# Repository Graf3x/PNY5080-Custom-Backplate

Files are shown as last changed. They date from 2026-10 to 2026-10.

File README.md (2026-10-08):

# PNY5080-Custom-Backplate

A white laser-cut backplate and a folded-metal cable cover for the **PNY GeForce RTX 5080 OC Triple Fan**. The 12V-2x6 power cable runs down a channel across the back of the card instead of sticking straight up out of the top.

Everything is generated from Python, and that python was FULLY vibe coded, make sure you use the test-prints on paper before you commit to getting something cut.  The cut files in this repo are the exact v94 files I ordered from SendCutSend, and the code rebuilds them to the micron. I take no liability if things do not line up for you. 

**The build story:** [Building a white, cable-hidden RTX 5080 with Claude](https://graf3x.github.io/PNY5080-Custom-Backplate/). How it went, including everything that didn't work.

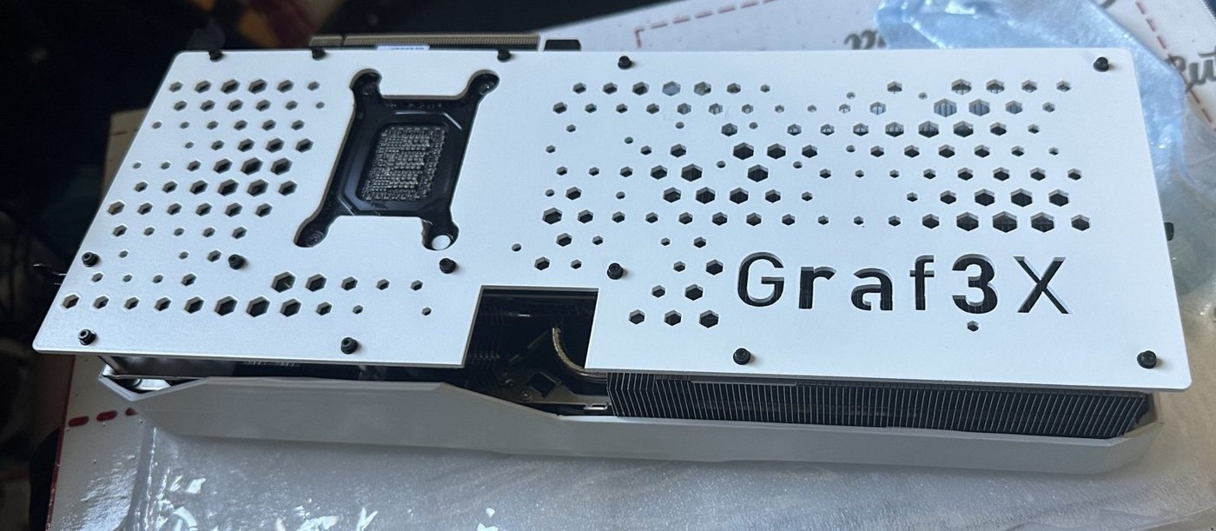
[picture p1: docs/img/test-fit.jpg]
First test fit: every screw seated


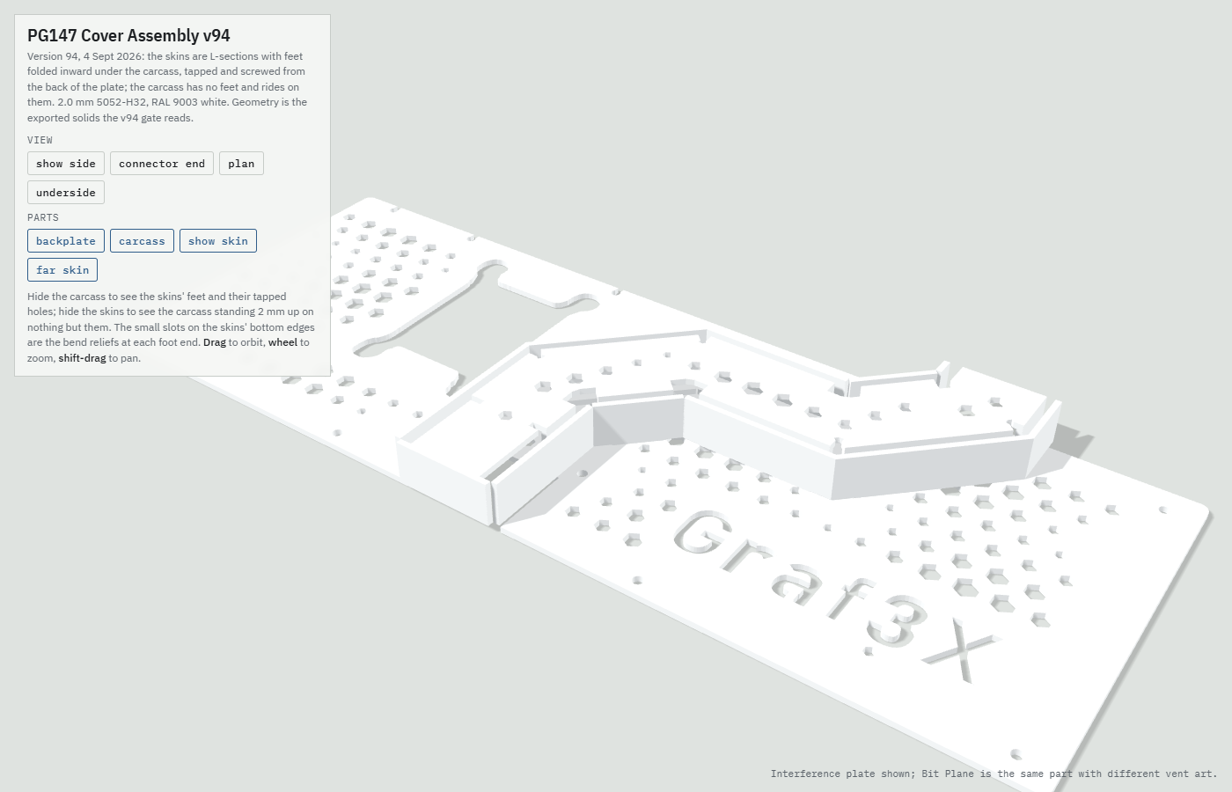
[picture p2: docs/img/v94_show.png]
v94 render
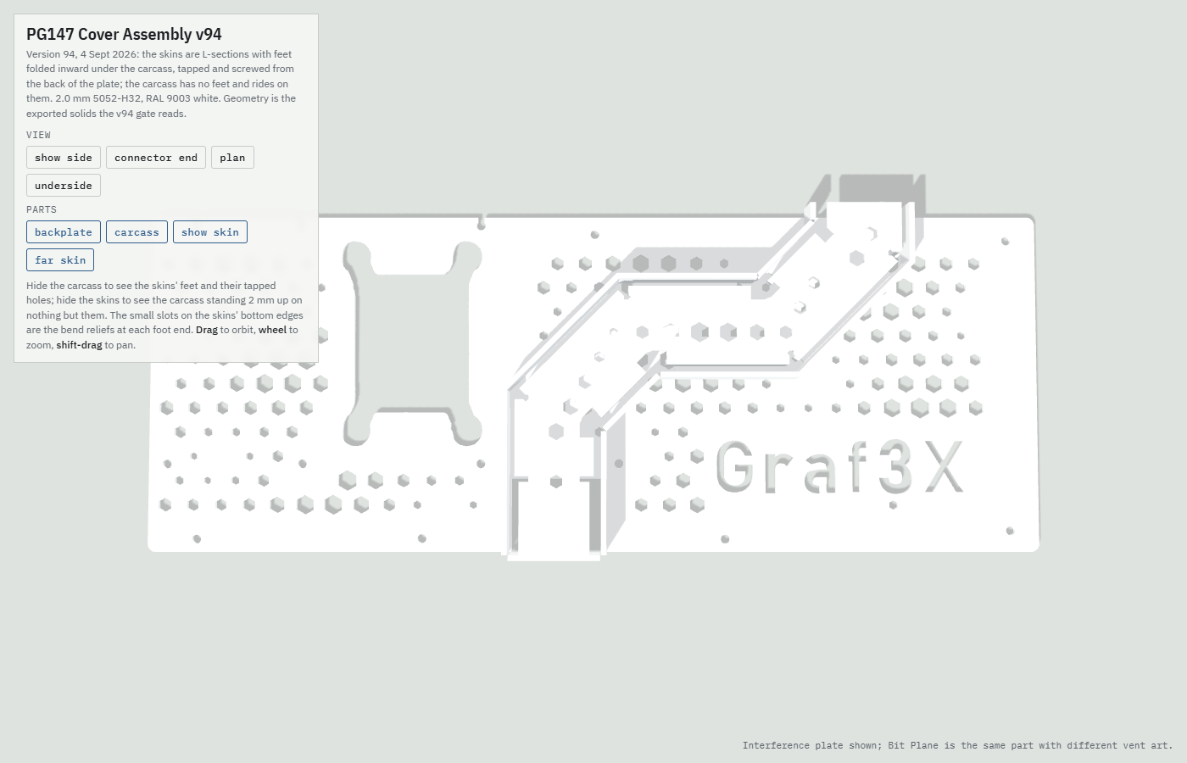
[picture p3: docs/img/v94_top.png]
v94 plan view
|  |  |
|---|---|
| The v94 assembly | Plan view, with the vent field running under the channel |

---

## Read this before you cut anything

- **It fits one card.** The 13 screw holes were measured from a PNY RTX 5080 OC Triple Fan (`VCG508016TFXPB1-O`, board **PG147 SKU 45**) using 300 dpi flatbed scans and calipers. Other 5080s, including other PNY models, are different boards. If yours isn't this exact card, assume the holes are wrong until you've proven otherwise.
- **Print the paper templates first.** Lay them on your card. If every hole and edge doesn't line up on paper, it won't line up in metal. A sheet of printer paper costs about 1.4 cents. A plate costs about $68 for just the backplate (not the channel) and a week of shipping.
- **You are modifying a graphics card.** Taking the stock backplate off, re-padding and re-fitting are on you. No warranty of any kind comes with these files.

## What's in here

```
out/production_v94/upload/   the files you upload to SendCutSend, plus ORDER_SHEET_v94.txt
out/production_v94/          the same parts with notes drawn beside them, for reading
out/production_v94/templates_1to1_letter.pdf / _a4.pdf   paper templates, print at 100%
out/render_v94/              3D files of the assembly (GLB) for looking at
reference/v94-as-ordered/    a frozen copy of the exact files that were cut
cad/                         the Python that generates all of it
tools/print_templates.py     draws 1:1 templates from any folder of DXFs
tools/compare_dxf.py         checks two sets of cut files for identical geometry
```

## The parts

All five parts are **2.0 mm (0.080 in) 5052-H32 aluminium**, powder coated **RAL 9003 signal white**. Every part is over SendCutSend's 1 inch minimum for powder coat.

| File | What it is |
|---|---|
| `backplate_interference_v94.dxf` | Backplate with the Interference vent field |
| `backplate_bit_plane_v94.dxf` | The same backplate with the Bit Plane vent field. Order one or both. |
| `carcass_v94.dxf` | The cable channel itself. One piece, 10 folds, all 90° and all the same way. |
| `skin_show_v94.dxf` | The outer wall on the logo side. 4 × 45° folds plus 3 inward feet, 5 tapped holes. |
| `skin_far_v94.dxf` | The outer wall on the other side. 4 × 45° folds plus 4 inward feet, 6 tapped holes. |

The DXF layers tell the vendor everything:

- `CUT` is the laser line.
- `BEND_UP_45`, `BEND_DOWN_45` and `BEND_DOWN_90` are dashed fold lines, with the direction and angle in the name. UP means toward the reader of the file.
- `TAP` is drill and tap, not laser.

`ORDER_SHEET_v94.txt` spells all of this out for the order.

### Hardware

| Item | Used for |
|---|---|
| 11 × M2.5 × 0.45 × 4 mm flat head screws (90°) | Plate to the skins' feet, driven from the back |
| 3M VHB 4991, 2.30 mm, grey | Carcass to the inner faces of the skins. The grey reads as a shadow line. |
| M2 screws | Plate to the card's 13 mounting points |
| [Ktehloy metric threaded insert kit](https://www.amazon.com/dp/B0CLKDPN65) | Standoffs at the mounting points that don't touch the PCB |
| Nylon washers, or silicone washers cut to size | Spacers at the mounting points on the PCB itself |

The stock plate was dimpled to a different depth at each screw, and a flat plate can't do that. So every mounting point needs its own spacer height. Set each one to fit before you tighten anything, or the screws will pull the plate into a bow. The clearance holes are 3.2 mm on purpose, so a washer under each screw head helps spread the load.

The cover was designed around a 180° 12V-2x6 adapter about 30 × 25 × 12.6 mm and a cable bundle about 22 × 6 mm.

## Quick start: order exactly what I built

1. Print `out/production_v94/templates_1to1_letter.pdf` (or `_a4.pdf`) at **100% / Actual size**. Never "Fit to page".
2. Measure the 100 mm bar on each sheet with a ruler. If it isn't 100 mm, your printer scaled it. Fix that first.
3. Lay the backplate sheets on your card **ink up** and check every screw hole. The backplate spans two sheets that overlap. Line them up on the dashed seam marks and don't butt the paper edges together.
4. Cut out and fold the carcass and skins in card stock. Fold on the dashed lines in the direction each one is labelled. UP means toward you, the printed side.
5. Upload the five DXFs in `out/production_v94/upload/` to SendCutSend and follow `ORDER_SHEET_v94.txt`.

### Assembly

1. Countersink the backplate's 11 cover holes from the **back**, by hand, after coating (90°). SendCutSend won't countersink stock this thin.
2. Stand each skin on the plate with its feet inward. Drive the M2.5 flat heads from the back of the plate into the tapped feet.
3. Put the VHB tape on the skins' inner faces, drop the carcass in between them onto the feet, and press.
4. Fit the plate to the card with the M2 screws. Use threaded inserts as standoffs where the plate meets the cooler or brackets, and nylon or silicone washers where it meets the PCB.

## Rebuilding the files yourself

You need Python 3.12. The library versions in `requirements.txt` are pinned to the ones that built the cut files.

```bash
python -m venv .venv
.venv/Scripts/activate            # Windows (on macOS/Linux: source .venv/bin/activate)
pip install -r requirements.txt

python cad/make_v94.py            # the five DXFs + ORDER_SHEET into out/production_v94/
python cad/gate_v94.py            # the release checks: must end with ALL CHECKS PASS
python cad/export_v94.py          # 3D files into out/render_v94/
python tools/print_templates.py   # paper templates (add --paper a4 for A4)
```

To confirm your build matches what was actually cut:

```bash
python tools/compare_dxf.py out/production_v94/upload reference/v94-as-ordered
```

### Fonts

The wordmark is set in **Bahnschrift**, which ships with Windows 10 and 11. Fonts are not included in this repo because Microsoft's fonts can't be redistributed. `cad/config.py` looks for the font in the usual Windows, macOS and Linux font folders. To use a font file anywhere else:

```bash
set PNY5080_FONT=C:\path\to\YourFont.ttf      # Windows
export PNY5080_FONT=/path/to/YourFont.ttf     # macOS / Linux
```

## Customizing

The safe loop for **any** change is the same every time:

1. Edit the setting.
2. `python cad/vent_ocr.py` if you touched the logo. Every design must say **PASS**.
3. `python cad/make_v94.py`
4. `python cad/gate_v94.py`. It must end with **ALL CHECKS PASS**. The gate re-measures the actual files for metal thinner than 2 mm, holes too close to bends, feet that collide when folded and more. It also plants defects on purpose to prove its own checks still work.
5. `python tools/print_templates.py` and do the paper test on your card again.

### Change the logo text

In `cad/config.py`:

```python
class BRAND:
    TEXT = "Graf3X"
```

Use letters and digits only. The readability check has templates for A–Z, a–z and 0–9 and nothing else. After you change it, run `python cad/vent_ocr.py`. It renders each backplate, reads the logo back with a simple OCR and fails if any letter reads as something else.

It will fail sometimes, and that's the point. Some real results:

| Text | Result |
|---|---|
| `Graf3X`, `Grafex`, `PG147` | PASS on all three designs |
| `Josh` | FAIL. Reads "JnSh": the little bridge that holds the middle of the "o" in place makes it look like an "n". |
| `JOSH` | FAIL. Reads "J0SH": in Bahnschrift a capital O and a zero are nearly the same shape. |

When it fails, try one of these:

- Fewer characters, so each one is bigger.
- A wider mark. `MARK_W` in `cad/vent_iterate.py` is the mark's width in mm (90 by default) and `MARK_CENTRE` is where it sits on the plate.
- Different letters or capitalization. Watch out for pairs that look alike in your font, such as O and 0.

The design names in the code still say "Graf3X" (for example `"Interference / Graf3X, OCR"`). They're only labels. The text that gets cut comes from `BRAND.TEXT`.

### Change the font

Point `BRAND.FONT` in `cad/config.py` at a `.ttf` file, or set `PNY5080_FONT`. Not every font can be cut in 2 mm aluminium. Thin strokes and tight counters leave metal webs under 2 mm, and the gate will catch them. Arial Bold failed for exactly this reason, which is why the plate uses Bahnschrift. Bold, open, geometric faces have the best odds.

### Pick which vent designs become backplates

`PLATES` in `cad/make_production.py` lists the designs the build cuts:

```python
PLATES = ("Interference / Graf3X, OCR", "Bit Plane / Graf3X, OCR")
```

A third verified design, `"Interference long wave / Graf3X, OCR"`, is defined in `cad/vent_ocr.py`. Add it to `PLATES` and the build will emit a third backplate. The vent field stays clear of the thermal pads, the card screws and the area where the cover is attached.

### Change the finish

Colour and finish only matter on the order. Any powder SendCutSend offers will work. Keep every visible part on one order, because powder batches drift.

### Fitting a different card

This is real work, not a setting. The hole positions are in `cad/hole_pattern.py`, measured from one plate. The outline, die window and connector notch are in `cad/backplate_v3.py` and `cad/die_window.py`, and the cable route is in `cad/cover_ribbon.py` and `cad/v94.py`. If you go down this road, measure your own stock backplate, change those numbers, and lean hard on the paper templates.

## License

**CC BY-NC 4.0.** You can use, change and share these files for non-commercial purposes as long as you give credit. Selling the files or parts made from them is not allowed. See `LICENSE` for the full terms. © 2026 Data Disruptors LLC (Grafex).

PNY, NVIDIA, GeForce, SendCutSend, 3M and VHB are trademarks of their respective owners. This project is not affiliated with or endorsed by any of them.

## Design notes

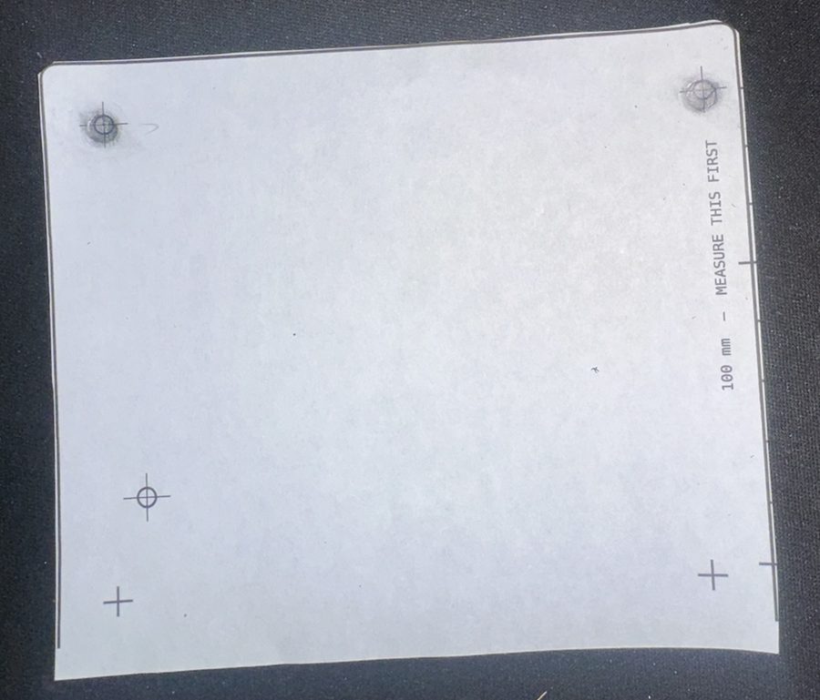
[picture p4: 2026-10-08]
docs/writeup-img/14-79dea924b6.jpg

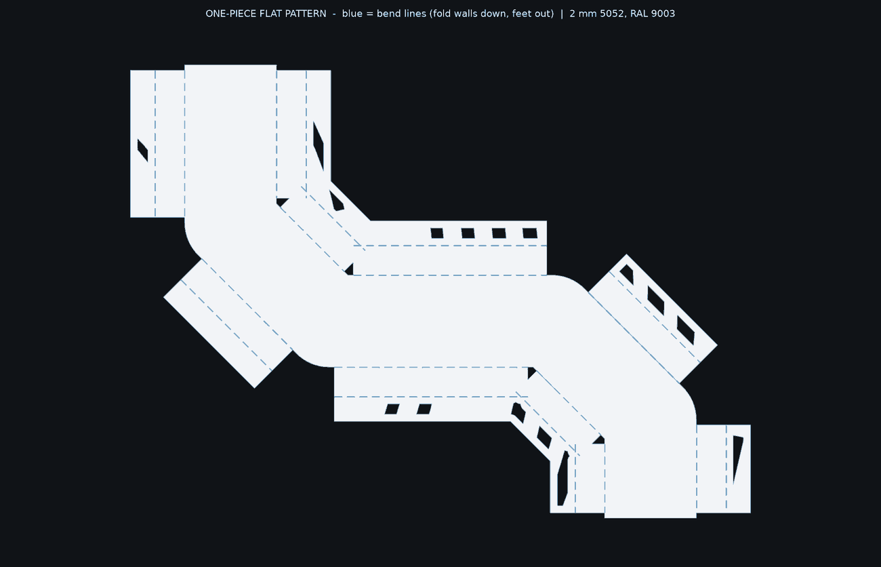
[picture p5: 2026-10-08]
docs/writeup-img/04-ba247a8842.png

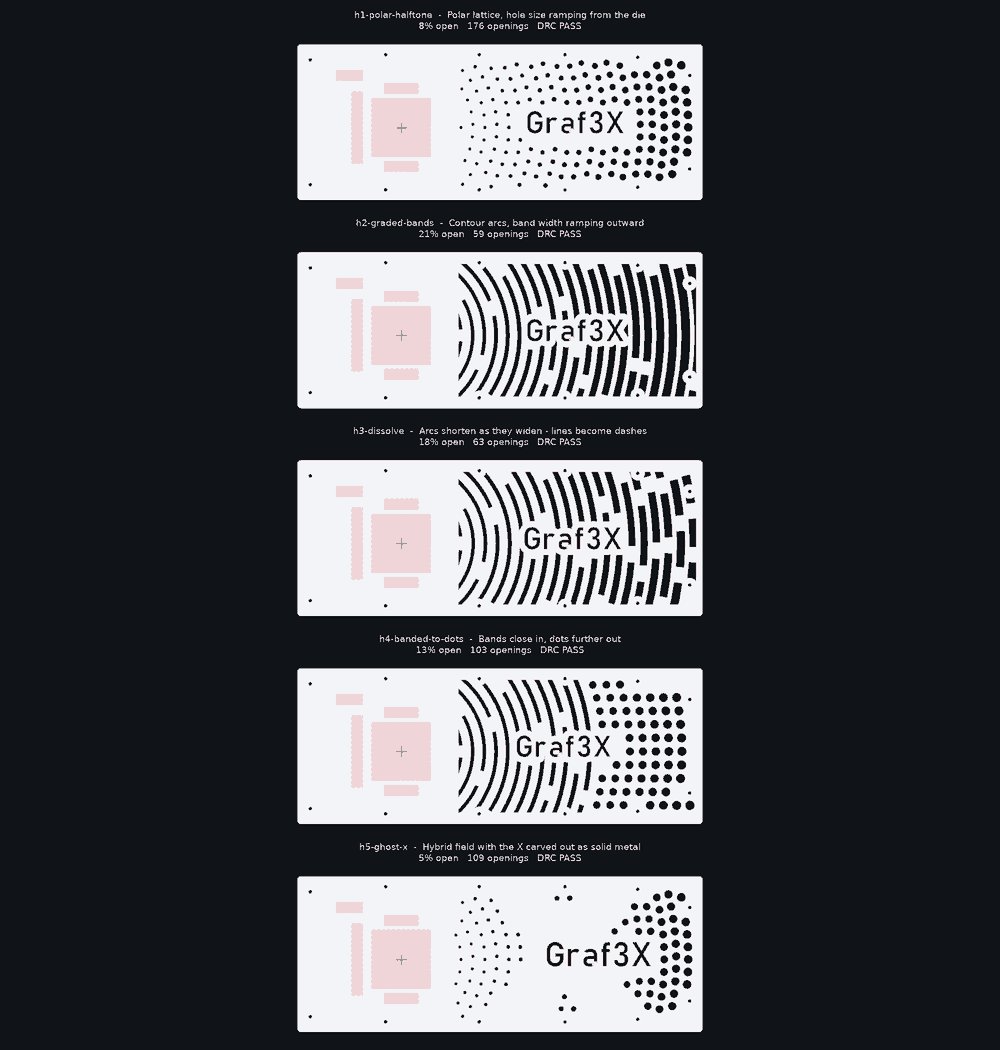
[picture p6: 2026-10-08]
docs/writeup-img/06-0ba101b55b.png

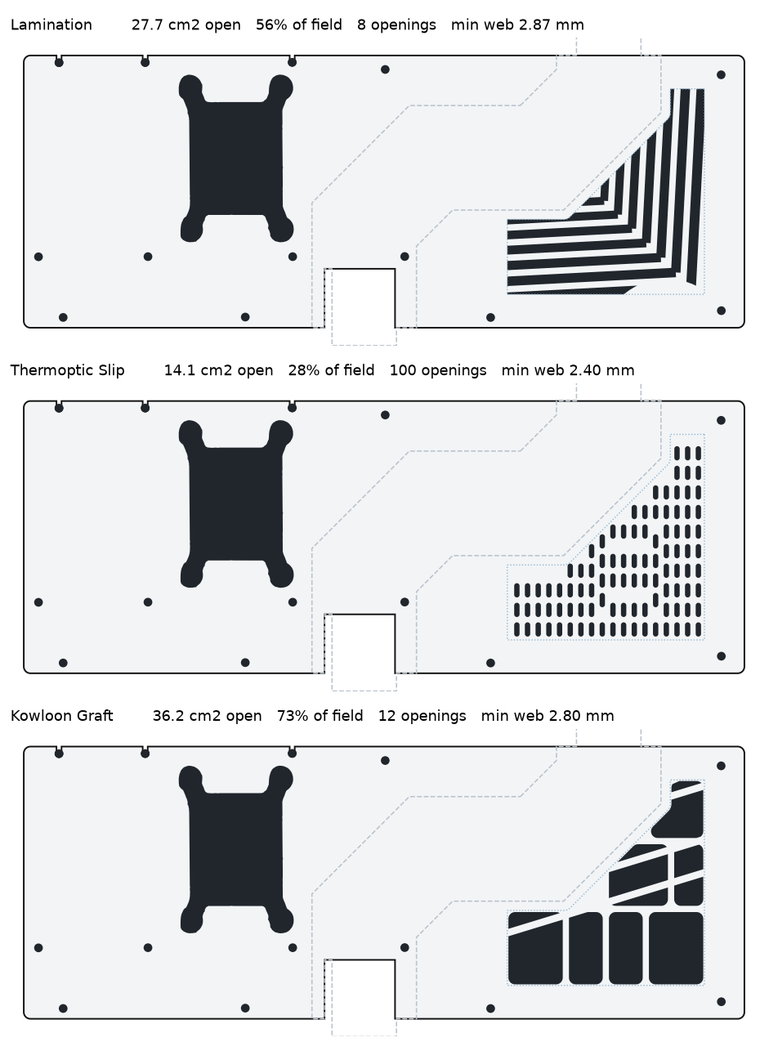
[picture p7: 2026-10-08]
docs/writeup-img/17-3ee478ab25.png

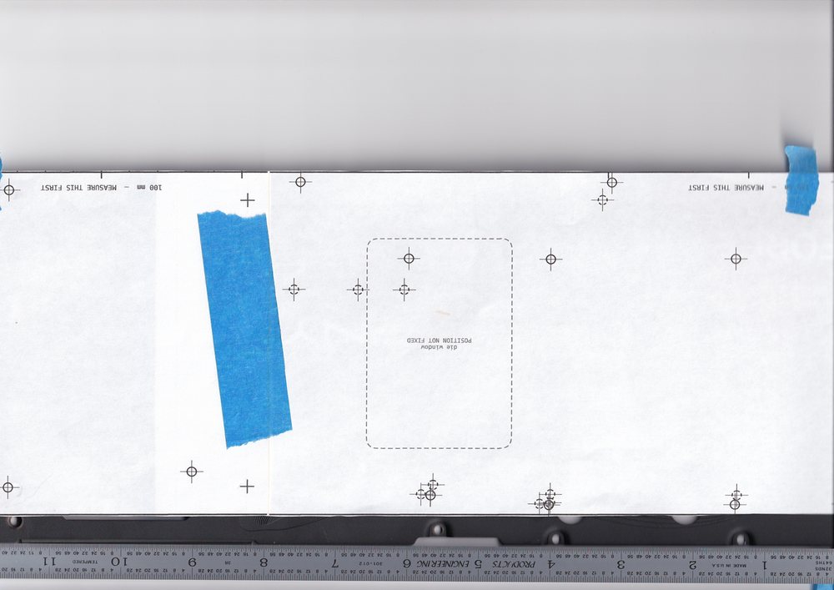
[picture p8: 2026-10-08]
docs/writeup-img/10-968c5388d2.jpg

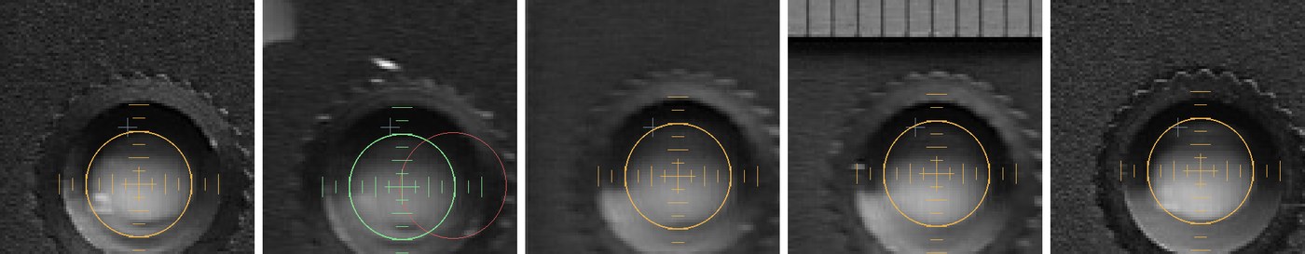
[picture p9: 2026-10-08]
docs/writeup-img/16-f5f942da19.jpg

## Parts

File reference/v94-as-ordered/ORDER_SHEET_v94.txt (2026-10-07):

PG147 COVER - ORDER SHEET v94  (SendCutSend)

MATERIAL  5052-H32 aluminium, 0.080 in (2.0 mm), all five parts.
FINISH    powder coat RAL 9003 signal white, matte or gloss - the
          same on all five. Every part is now over the 1 in powder
          minimum: skins 27.35 mm (1.077 in) wide in the flat.
QUANTITY  1 of each: backplate_bit_plane_v94.dxf, backplate_interference_v94.dxf, carcass_v94.dxf, skin_far_v94.dxf, skin_show_v94.dxf

LAYERS    CUT = laser.  BEND_UP_45 / BEND_DOWN_45 / BEND_DOWN_90 =
          dashed fold lines, direction + angle in the name. UP =
          toward the reader of the file. TAP = drill + tap, not laser.

BACKPLATES  2, interchangeable. 11 x dia 2.90 clearance for the
          cover screws, on CUT. No slots, no taps. The owner
          countersinks these from the BACK by hand after coating
          (90 deg, M2.5 x 0.45 flat head) - the vendor countersinks
          0.125 in and thicker only.

CARCASS   one piece, 10 folds, all 90 deg, all BEND_DOWN_90: nine
          walls and the end cap, all away from the reader. NO feet.
          16 roof vents on CUT. It stands on the skins' feet and is
          bonded to the skins with 3M VHB 4991, 2.30 mm, grey.

SKIN SHOW  199.63 x 27.35 mm flat. 4 x 45 deg folds (two each way) +
          3 foot folds at 90 deg on BEND_DOWN_90, INWARD. 5 tapped
          M2.5 x 0.45 on layer TAP. 6 relief slots 2.0 x 3.47 on the
          bottom edge, one at each foot end - required.
SKIN FAR   199.63 x 27.35 mm flat. 4 x 45 deg folds (two each way) +
          4 foot folds at 90 deg on BEND_DOWN_90, INWARD. 6 tapped
          M2.5 x 0.45 on layer TAP. 8 relief slots 2.0 x 3.47 on the
          bottom edge, one at each foot end - required.

ASSEMBLY  1. Countersink the plate's 11 holes from the back.
          2. Stand each skin on the plate, feet inward, and drive
             M2.5 x 0.45 x 4 flat heads from the back into the feet.
          3. Apply 3M VHB 4991, 2.30 mm, grey to the skins' inner faces,
             drop the carcass in between them onto the feet, press.
          Stack: plate 2.00 + skin foot 2.00 (+coats) = carcass wall
          bottom at 4.45; roof top at 16.95; cable clear height 10.65.
HARDWARE  11 x M2.5 x 0.45 x 4 mm flat head (90 deg), stainless or black.

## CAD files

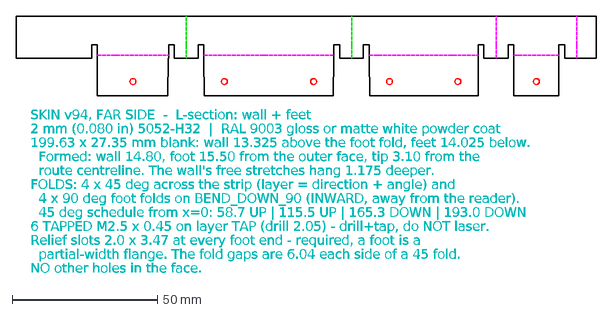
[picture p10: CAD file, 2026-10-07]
out/production_v94/skin_far_v94.dxf
SKIN v94, FAR SIDE - L-section: wall + feet
2 mm (0.080 in) 5052-H32 | RAL 9003 gloss or matte white powder coat
199.63 x 27.35 mm blank: wall 13.325 above the foot fold, feet 14.025 below.
Formed: wall 14.80, foot 15.50 from the outer face, tip 3.10 from the
route centreline. The wall's free stretches hang 1.175 deeper.
FOLDS: 4 x 45 deg across the strip (layer = direction + angle) and
4 x 90 deg foot folds on BEND_DOWN_90 (INWARD, away from the reader).
45 deg schedule from x=0: 58.7 UP | 115.5 UP | 165.3 DOWN | 193.0 DOWN
6 TAPPED M2.5 x 0.45 on layer TAP (drill 2.05) - drill+tap, do NOT laser.
Relief slots 2.0 x 3.47 at every foot end - required, a foot is a
partial-width flange. The fold gaps are 6.04 each side of a 45 fold.
NO other holes in the face.

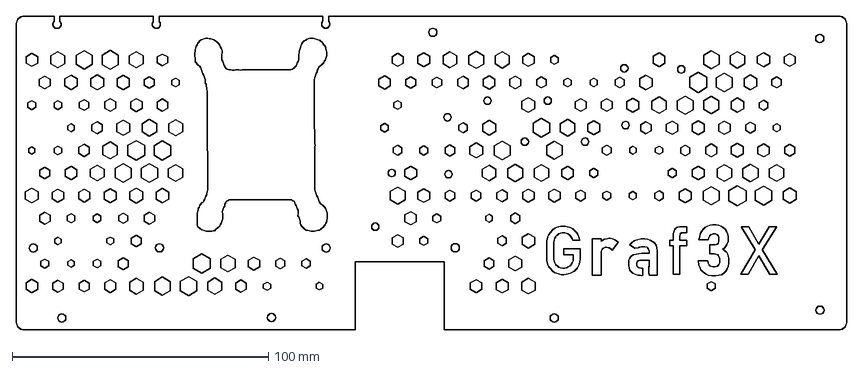
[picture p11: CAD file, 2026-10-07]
out/production_v94/upload/backplate_interference_v94.dxf
324.0 x 122.4 mm

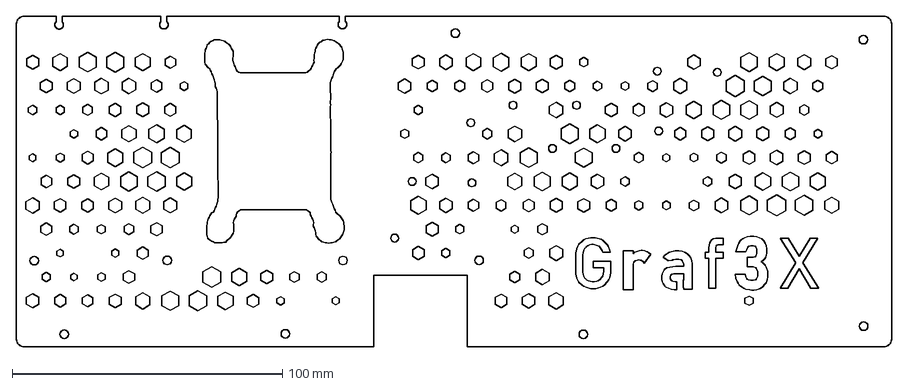
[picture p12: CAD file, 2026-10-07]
reference/v94-as-ordered/backplate_interference_v94.dxf
324.0 x 122.4 mm

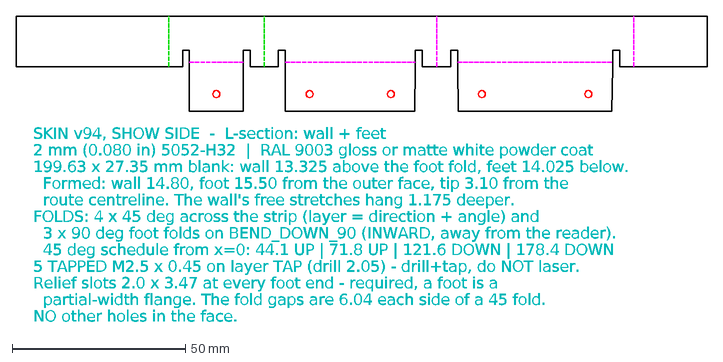
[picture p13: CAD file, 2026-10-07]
out/production_v94/skin_show_v94.dxf
SKIN v94, SHOW SIDE - L-section: wall + feet
2 mm (0.080 in) 5052-H32 | RAL 9003 gloss or matte white powder coat
199.63 x 27.35 mm blank: wall 13.325 above the foot fold, feet 14.025 below.
Formed: wall 14.80, foot 15.50 from the outer face, tip 3.10 from the
route centreline. The wall's free stretches hang 1.175 deeper.
FOLDS: 4 x 45 deg across the strip (layer = direction + angle) and
3 x 90 deg foot folds on BEND_DOWN_90 (INWARD, away from the reader).
45 deg schedule from x=0: 44.1 UP | 71.8 UP | 121.6 DOWN | 178.4 DOWN
5 TAPPED M2.5 x 0.45 on layer TAP (drill 2.05) - drill+tap, do NOT laser.
Relief slots 2.0 x 3.47 at every foot end - required, a foot is a
partial-width flange. The fold gaps are 6.04 each side of a 45 fold.
NO other holes in the face.

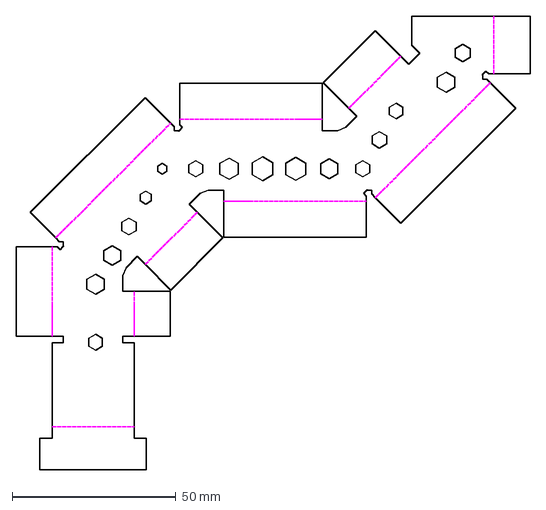
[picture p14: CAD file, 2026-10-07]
out/production_v94/upload/carcass_v94.dxf
157.0 x 138.4 mm

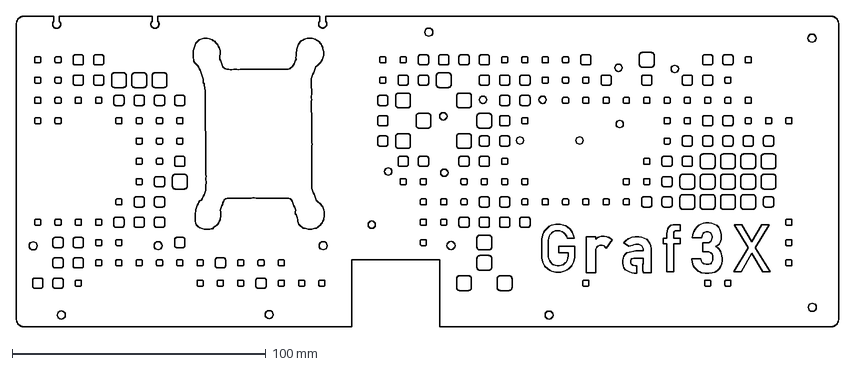
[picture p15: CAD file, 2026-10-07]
reference/v94-as-ordered/backplate_bit_plane_v94.dxf
324.0 x 122.4 mm

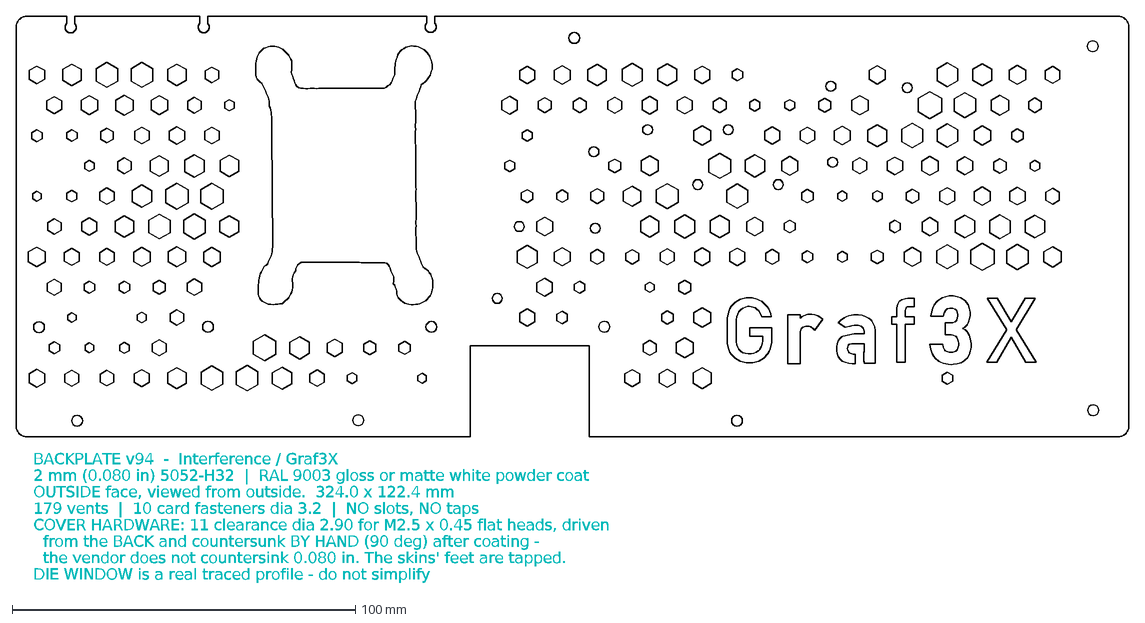
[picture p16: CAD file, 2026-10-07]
out/production_v94/backplate_interference_v94.dxf
BACKPLATE v94 - Interference / Graf3X
2 mm (0.080 in) 5052-H32 | RAL 9003 gloss or matte white powder coat
OUTSIDE face, viewed from outside. 324.0 x 122.4 mm
179 vents | 10 card fasteners dia 3.2 | NO slots, NO taps
COVER HARDWARE: 11 clearance dia 2.90 for M2.5 x 0.45 flat heads, driven
from the BACK and countersunk BY HAND (90 deg) after coating -
the vendor does not countersink 0.080 in. The skins' feet are tapped.
DIE WINDOW is a real traced profile - do not simplify

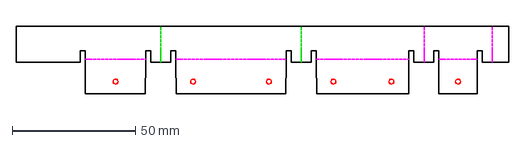
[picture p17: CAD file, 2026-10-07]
out/production_v94/upload/skin_far_v94.dxf
199.6 x 27.4 mm

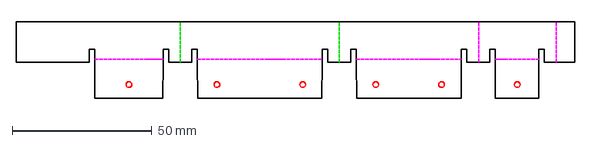
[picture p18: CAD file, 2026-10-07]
reference/v94-as-ordered/skin_far_v94.dxf
199.6 x 27.4 mm

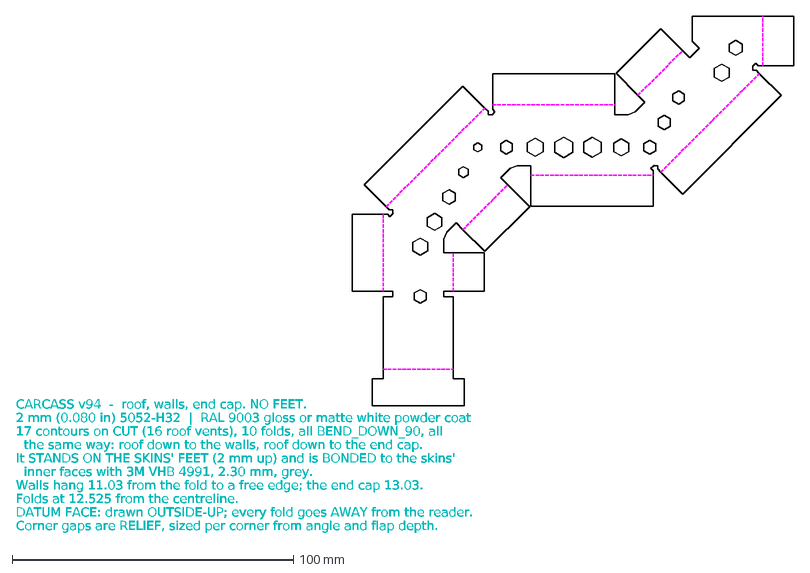
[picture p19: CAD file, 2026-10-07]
out/production_v94/carcass_v94.dxf
CARCASS v94 - roof, walls, end cap. NO FEET.
2 mm (0.080 in) 5052-H32 | RAL 9003 gloss or matte white powder coat
17 contours on CUT (16 roof vents), 10 folds, all BEND_DOWN_90, all
the same way: roof down to the walls, roof down to the end cap.
It STANDS ON THE SKINS' FEET (2 mm up) and is BONDED to the skins'
inner faces with 3M VHB 4991, 2.30 mm, grey.
Walls hang 11.03 from the fold to a free edge; the end cap 13.03.
Folds at 12.525 from the centreline.
DATUM FACE: drawn OUTSIDE-UP; every fold goes AWAY from the reader.
Corner gaps are RELIEF, sized per corner from angle and flap depth.

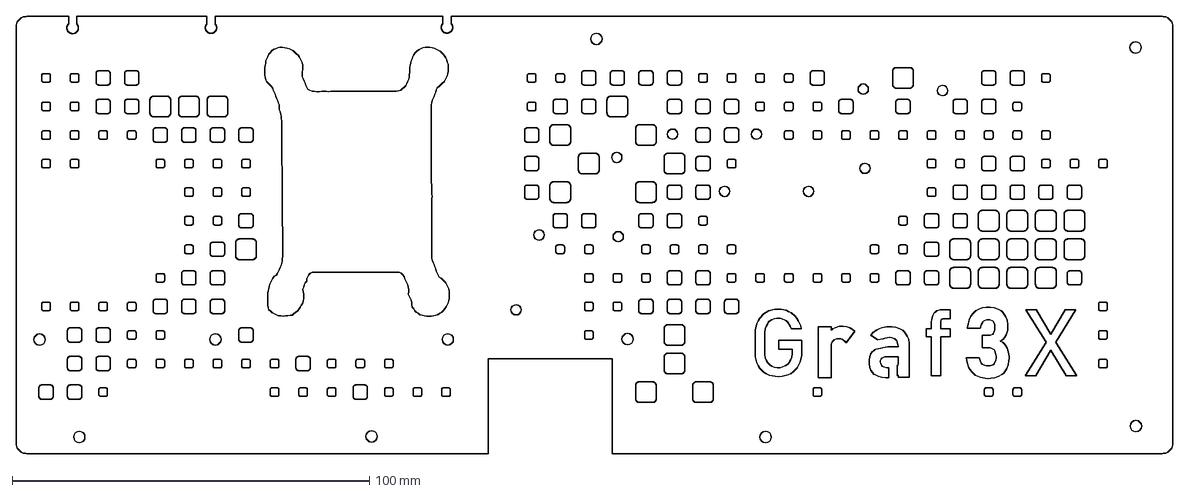
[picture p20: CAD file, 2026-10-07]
out/production_v94/upload/backplate_bit_plane_v94.dxf
324.0 x 122.4 mm

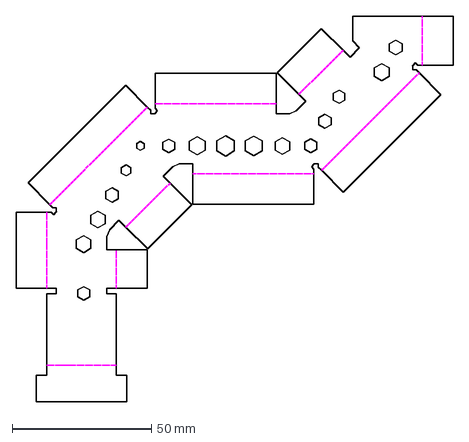
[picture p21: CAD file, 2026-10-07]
reference/v94-as-ordered/carcass_v94.dxf
157.0 x 138.4 mm

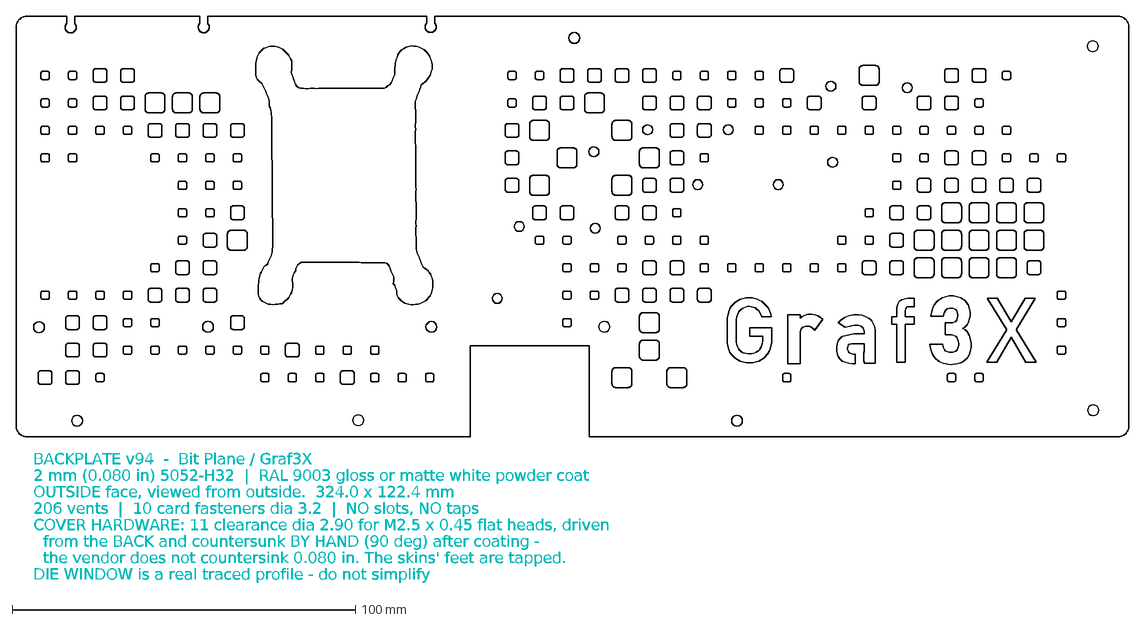
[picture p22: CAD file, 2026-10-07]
out/production_v94/backplate_bit_plane_v94.dxf
BACKPLATE v94 - Bit Plane / Graf3X
2 mm (0.080 in) 5052-H32 | RAL 9003 gloss or matte white powder coat
OUTSIDE face, viewed from outside. 324.0 x 122.4 mm
206 vents | 10 card fasteners dia 3.2 | NO slots, NO taps
COVER HARDWARE: 11 clearance dia 2.90 for M2.5 x 0.45 flat heads, driven
from the BACK and countersunk BY HAND (90 deg) after coating -
the vendor does not countersink 0.080 in. The skins' feet are tapped.
DIE WINDOW is a real traced profile - do not simplify

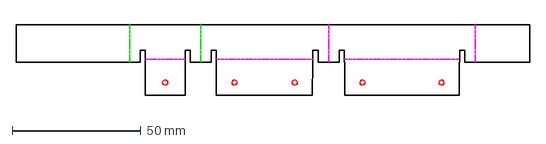
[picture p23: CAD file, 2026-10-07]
out/production_v94/upload/skin_show_v94.dxf
199.6 x 27.4 mm

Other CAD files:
reference/v94-as-ordered/skin_show_v94.dxf

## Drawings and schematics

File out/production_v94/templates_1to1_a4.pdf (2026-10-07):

# backplate_bit_plane_v94 - sheet 1 of 2

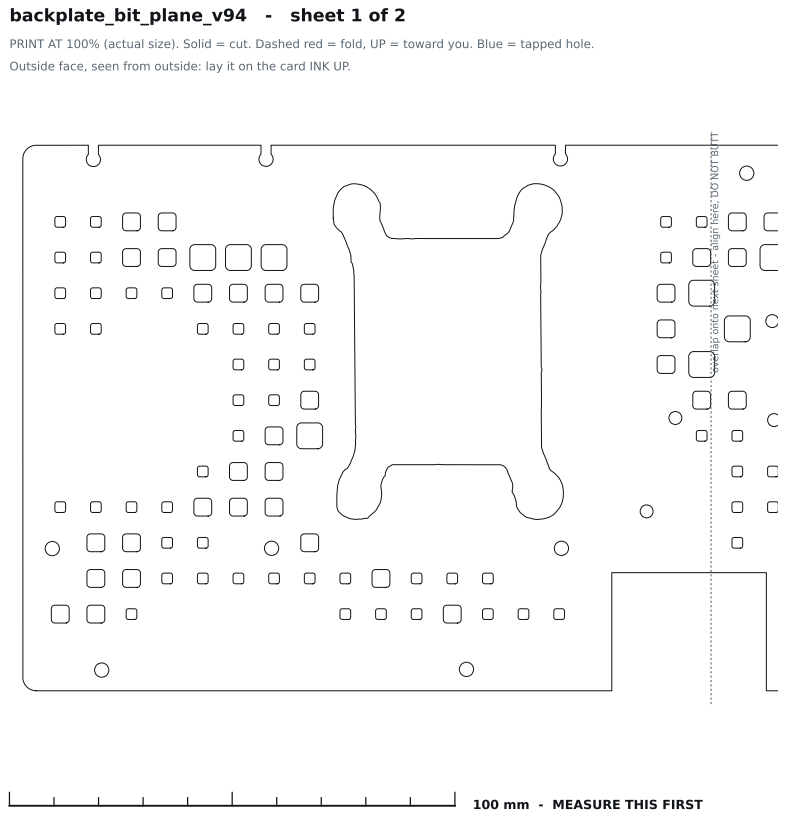
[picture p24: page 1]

PRINT AT 100% (actual size). Solid = cut. Dashed red = fold, UP = toward you. Blue = tapped hole.

Outside face, seen from outside: lay it on the card INK UP.

overlap onto next sheet - align here, DO NOT BUTT

100 mm - MEASURE THIS FIRST

# backplate_bit_plane_v94 - sheet 2 of 2

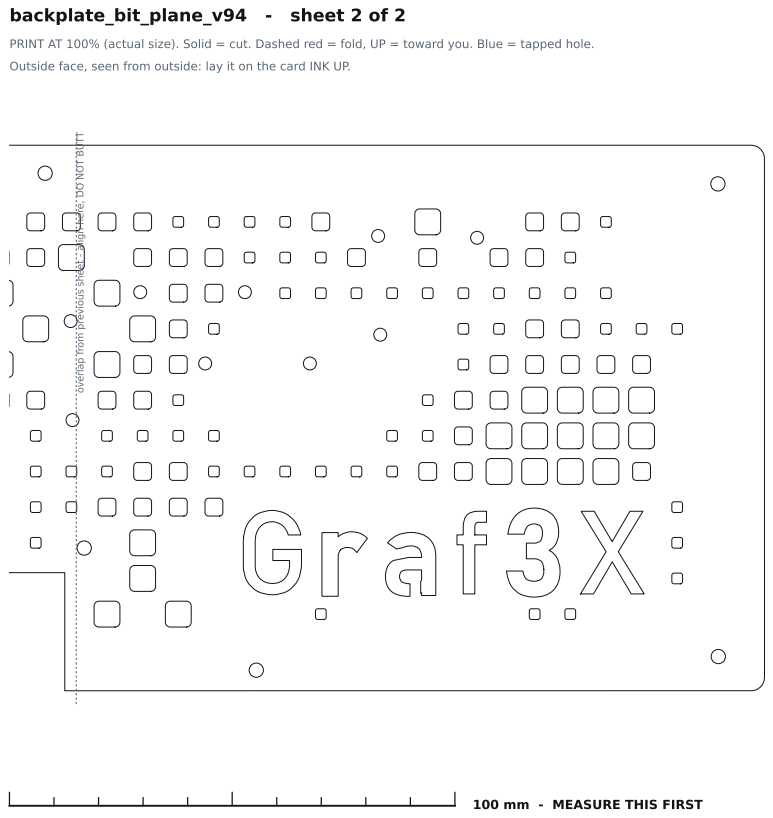
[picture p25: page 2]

PRINT AT 100% (actual size). Solid = cut. Dashed red = fold, UP = toward you. Blue = tapped hole.

Outside face, seen from outside: lay it on the card INK UP.

overlap from previous sheet - align here, DO NOT BUTT

100 mm - MEASURE THIS FIRST

# backplate_interference_v94 - sheet 1 of 2

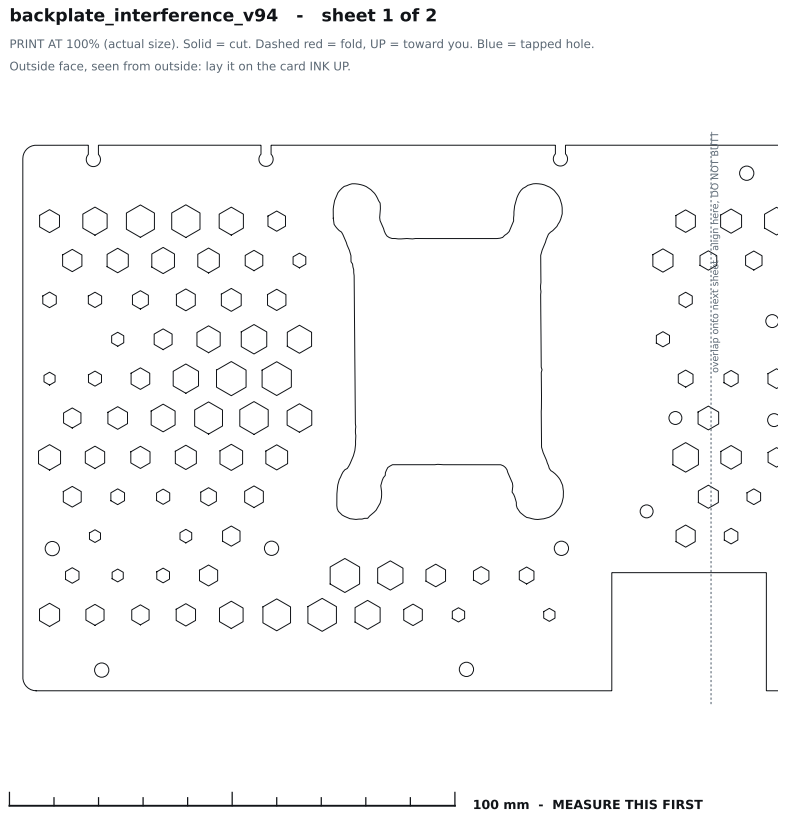
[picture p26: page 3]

PRINT AT 100% (actual size). Solid = cut. Dashed red = fold, UP = toward you. Blue = tapped hole.

Outside face, seen from outside: lay it on the card INK UP.

overlap onto next sheet - align here, DO NOT BUTT

100 mm - MEASURE THIS FIRST

# backplate_interference_v94 - sheet 2 of 2

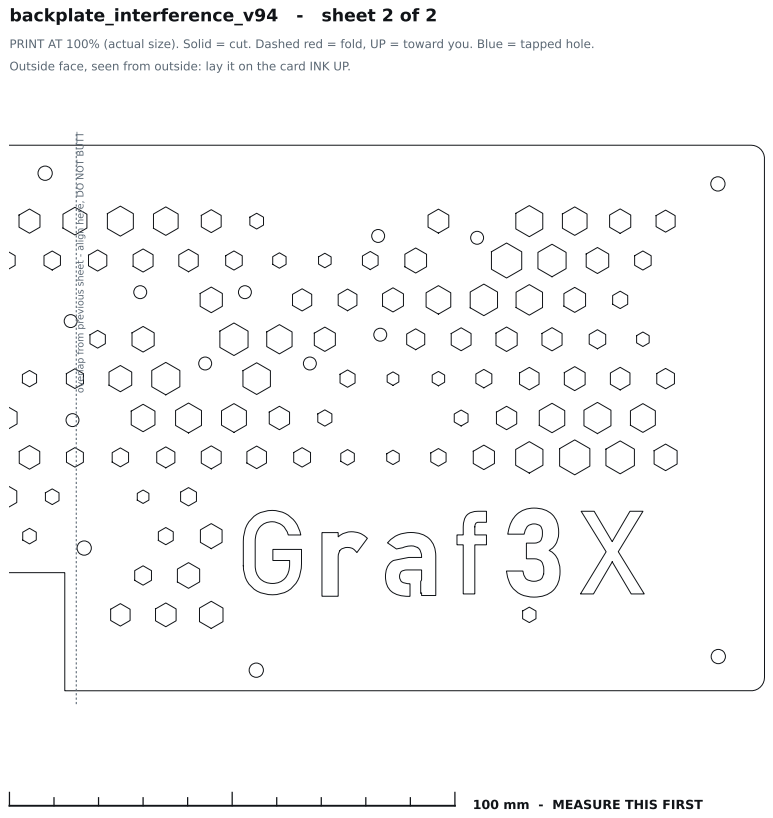
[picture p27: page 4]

PRINT AT 100% (actual size). Solid = cut. Dashed red = fold, UP = toward you. Blue = tapped hole.

Outside face, seen from outside: lay it on the card INK UP.

overlap from previous sheet - align here, DO NOT BUTT

100 mm - MEASURE THIS FIRST

# carcass_v94

PRINT AT 100% (actual size). Solid = cut. Dashed red = fold, UP = toward you. Blue = tapped hole.

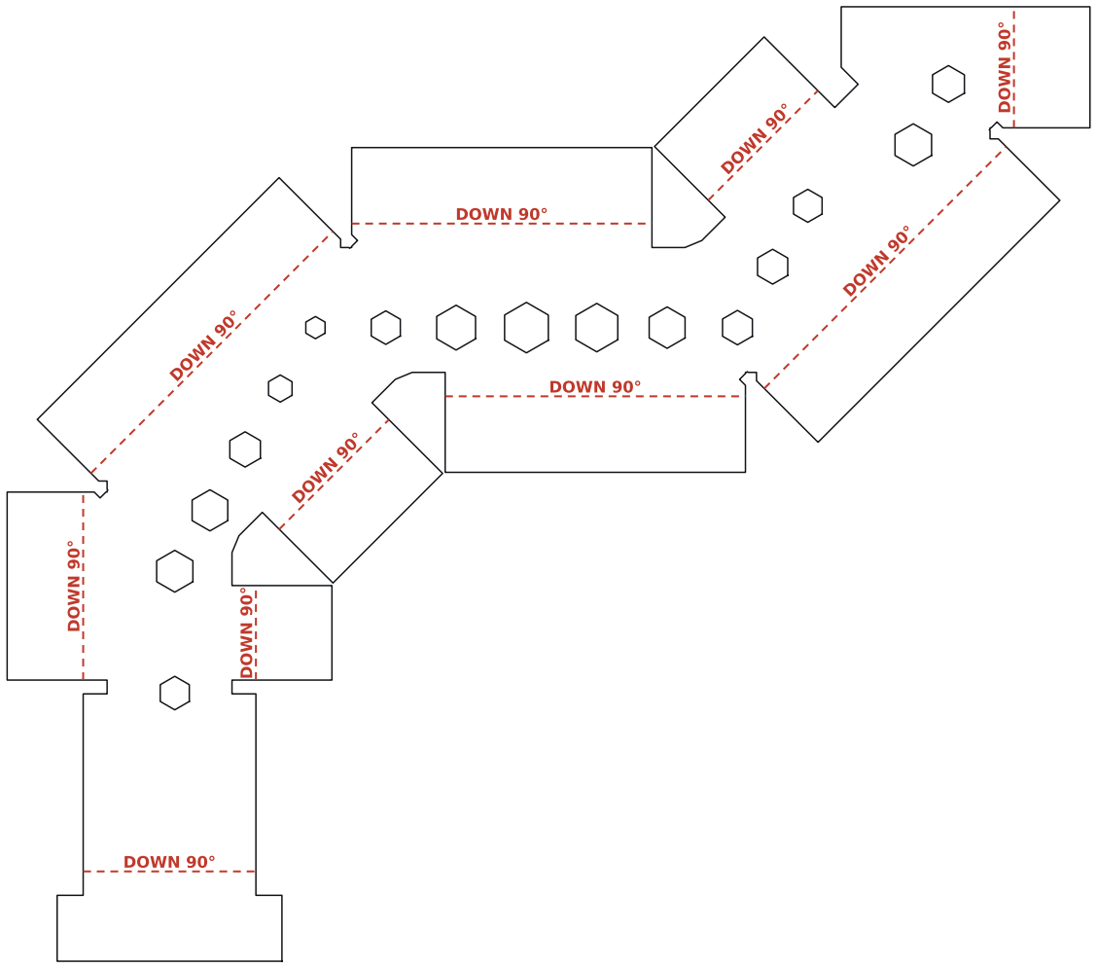
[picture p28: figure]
DOWN 90°

### 100 mm - MEASURE THIS FIRST

# skin_far_v94

PRINT AT 100% (actual size). Solid = cut. Dashed red = fold, UP = toward you. Blue = tapped hole.

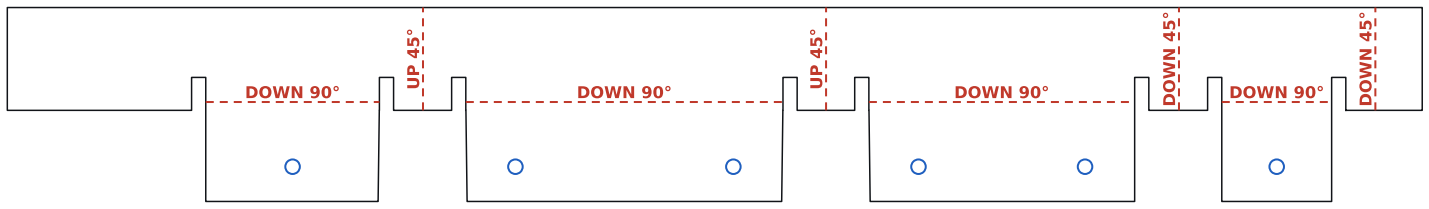
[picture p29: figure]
DOWN 45°; DOWN 90°

### 100 mm - MEASURE THIS FIRST

# skin_show_v94

PRINT AT 100% (actual size). Solid = cut. Dashed red = fold, UP = toward you. Blue = tapped hole.

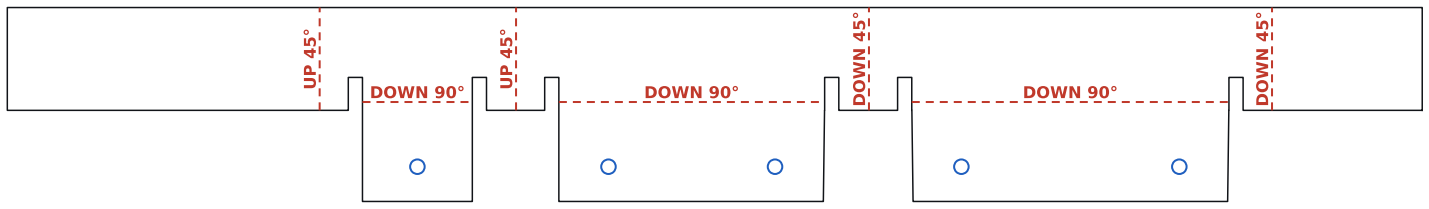
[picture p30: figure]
DOWN 45°; DOWN 90°

### 100 mm - MEASURE THIS FIRST

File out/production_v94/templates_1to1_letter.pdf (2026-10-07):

# backplate_bit_plane_v94 - sheet 1 of 2

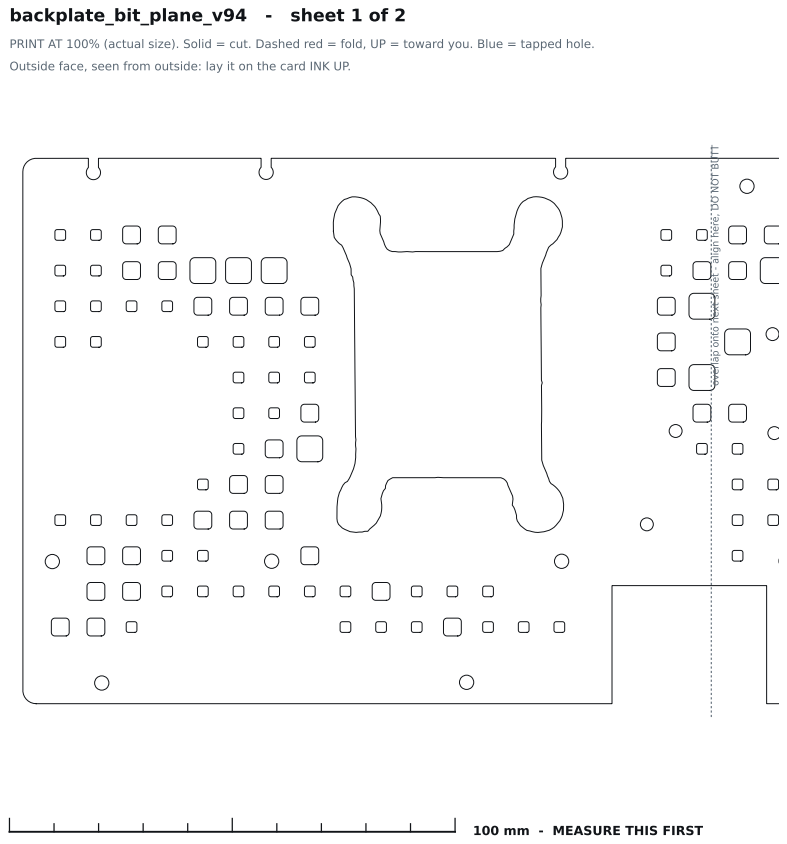
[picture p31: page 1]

PRINT AT 100% (actual size). Solid = cut. Dashed red = fold, UP = toward you. Blue = tapped hole.

Outside face, seen from outside: lay it on the card INK UP.

overlap onto next sheet - align here, DO NOT BUTT

100 mm - MEASURE THIS FIRST

# backplate_bit_plane_v94 - sheet 2 of 2

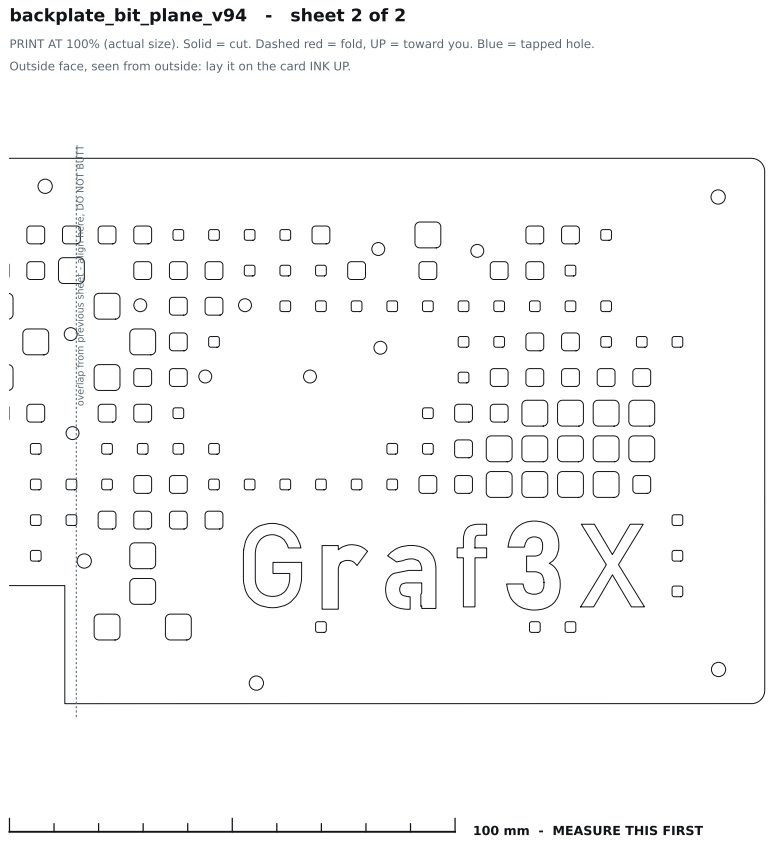
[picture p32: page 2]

PRINT AT 100% (actual size). Solid = cut. Dashed red = fold, UP = toward you. Blue = tapped hole.

Outside face, seen from outside: lay it on the card INK UP.

overlap from previous sheet - align here, DO NOT BUTT

# backplate_interference_v94 - sheet 1 of 2

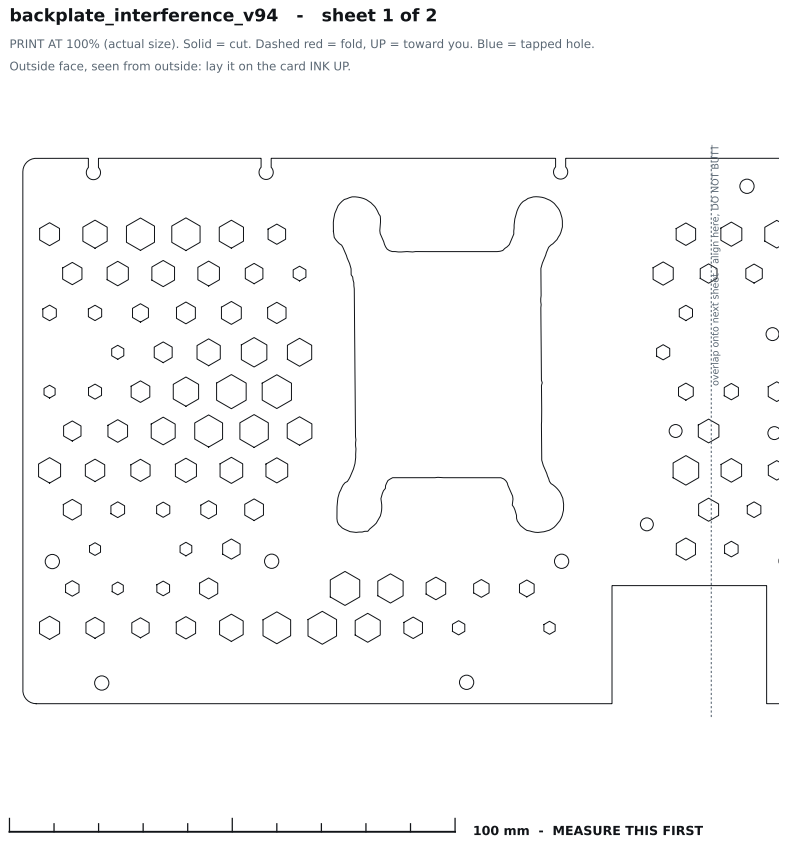
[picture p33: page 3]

PRINT AT 100% (actual size). Solid = cut. Dashed red = fold, UP = toward you. Blue = tapped hole.

Outside face, seen from outside: lay it on the card INK UP.

overlap onto next sheet - align here, DO NOT BUTT

# backplate_interference_v94 - sheet 2 of 2

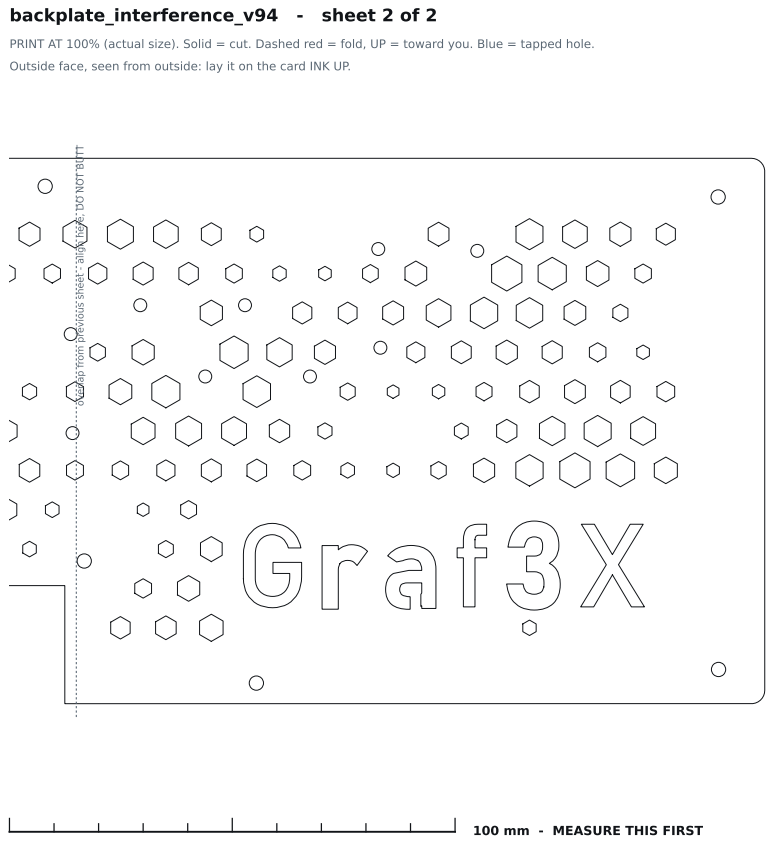
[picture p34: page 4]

PRINT AT 100% (actual size). Solid = cut. Dashed red = fold, UP = toward you. Blue = tapped hole.

Outside face, seen from outside: lay it on the card INK UP.

overlap from previous sheet - align here, DO NOT BUTT

# carcass_v94

PRINT AT 100% (actual size). Solid = cut. Dashed red = fold, UP = toward you. Blue = tapped hole.

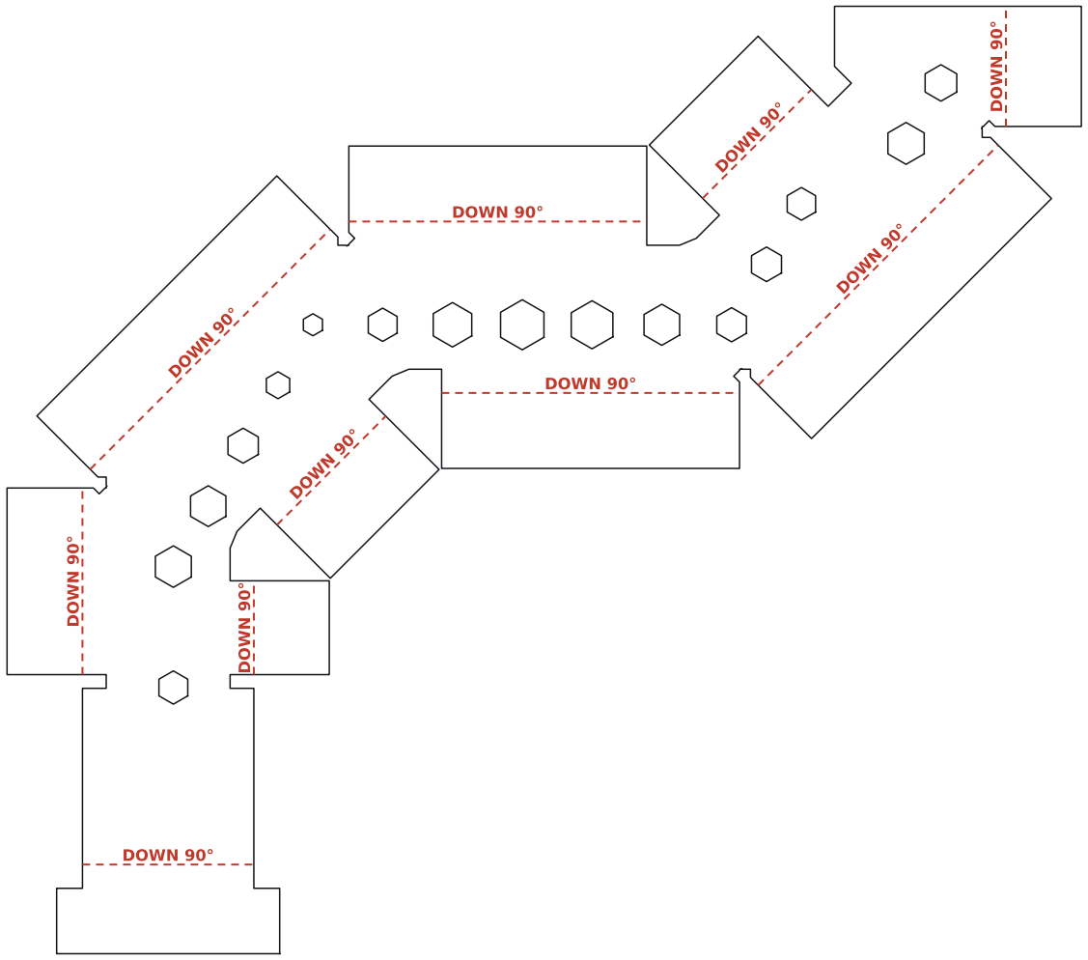
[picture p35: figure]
DOWN 90°

# skin_far_v94

PRINT AT 100% (actual size). Solid = cut. Dashed red = fold, UP = toward you. Blue = tapped hole.

DOWN 45°; DOWN 90°

# skin_show_v94

PRINT AT 100% (actual size). Solid = cut. Dashed red = fold, UP = toward you. Blue = tapped hole.

DOWN 45°; DOWN 90°

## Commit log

2026-10-07 PNY RTX 5080 custom backplate and cable cover, v94 as ordered
    The cut files, 1:1 paper templates and the Python that generates them for a
    white laser-cut backplate and folded aluminium cable cover on a PNY RTX 5080
    OC Triple Fan (board PG147 SKU 45).
    out/production_v94/upload is exactly what was sent to SendCutSend:
    cad/make_v94.py rebuilds it, and tools/compare_dxf.py confirms the rebuild
    matches reference/v94-as-ordered entity for entity to a micron.
    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
    [backplate_bit_plane_v94.dxf, backplate_interference_v94.dxf, carcass_v94.dxf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]
2026-10-07 README: the card hardware that was actually used
    Threaded inserts as standoffs where the plate meets the cooler and
    brackets, and nylon or cut silicone washers where it meets the PCB, in
    place of the nylon standoff kit from the original plan.
2026-10-07 Update README with Python usage and liability notice
    Clarified instructions regarding the Python code and test prints, and added a liability disclaimer.
2026-10-07 Clarify printing costs and remove design process section
    Updated the README to clarify printing costs and removed the section on design process.
